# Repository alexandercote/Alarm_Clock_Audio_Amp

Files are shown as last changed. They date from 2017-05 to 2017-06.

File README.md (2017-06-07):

# Alarm_Clock
Design class project where I worked in a group of 3 to implement a music playing alarm clock using a microcontroller board.
Features included displaying time on a 7 segment display, alarm buttons, snooze, ability to change time
and volume control. 

Each subfolder has README's describing the logic behind the decision and pictures demonstrating the contents of the files.

Alarm clock functionality:
- Change the displayed time, date, and alarm time.
- LED's indicate what mode you are currently in. 
     Modes include: Time/Date/Alarm Set, Snooze, and Default.
- Display time in both 12 hour(with AM/PM indicator) and 24 hour 
  formats.
- Choose from different songs placed on the internal storage (a 
  USB drive for our purposes)
- Change the volume of the song using a knob in the center.
- Snooze the alarm both with a push button on the case, and with your 
  phone over bluetooth.
- Use of external power supply (9V battery) for louder audio output.
- Ability to disable the alarm entirely and use it as a clock.

Demonstration of the alarm clock can be found in the following video:
https://www.youtube.com/watch?v=fe28Ro4kcdw

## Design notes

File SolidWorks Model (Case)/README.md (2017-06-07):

# The SolidWorks Case

A case was designed using SolidWorks.
## The Constraints
Designed to be 3D printed, so limited detail and constrained by 3D printing axis.
1. The Box
   - Hold the PCB inside.
   - Slot for 9V DC battery with access to terminal headers to unplug the battery
   - Hole in the back for pushbutton reset on the microcontroller board (STM)
  
The Box:
alarmclockbox_final-1

2. The Front Panel
   - A slot for the 7 segment display
   - Speaker mount
   - Five pushbutton hole slots
   - A potentiometer slot (Same size as pushbuttons)
   
The Front Plate/Panel:
frontplate_final-1

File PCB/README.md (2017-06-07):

# The Circuit

###### Design Limitation:
  - Have the following capacitors: 1nF, 10uF, 470uF and 100 nF
  - Resistors: 5% Resistors.
  - Input Voltage for audio input: [0-3V], DC voltage = 1.5V, with AC voltage = ± 0.3V. 
  - The audio input has source impedance of 20kΩ and has a maximum current source of 25mA.
  - From the data sheet, the impedance of the speaker is 8Ω.

Schematic view of the top hierarchy view, including push button debouncing, with an audio amplifier and LED multiplexer in lower hierarchy schematics.


###### Audio Amplifier:
  - Cascaded Low-Pass and High-Pass Filter to create a BandPass Filter with a pass band of 19.85Hz to 19.4kHz
  - Using the LM386 without its gain pins connected will result in a voltage gain of 20. Since (20 * 0.5V) = 10V, which is higher than 
    our source voltage, we need to voltage divide the input of LM386. (0.5V is the maximum input AC swing). Here, we chose a maximum 
    voltage of 4.5V to make sure the gain stays linear. From that, we found our values for resistors in the voltage divider. A 100kΩ
    potientiometer was used to dynamically set the gain (and therefore the volume)The potentiometer will always show 100 kΩ to the 
    High-Pass Filter, with the LM386 only seeing the resistance set in order to set the volume.

Schematic view of the audio amplifier schematic. Includes a low pass filter cascaded with a high-pass filter, a potentiometer for input voltage control, and an LM386 to amplify.


The schematic view of the LED multiplexing circuit:


The PCB (Two layer):

Top layer PCB view:

top pcb

Top layer view from the manufacturer (OshPark):



Bottom layer PCB view:

bottom pcb
Bottom layer view from the manufacturer:



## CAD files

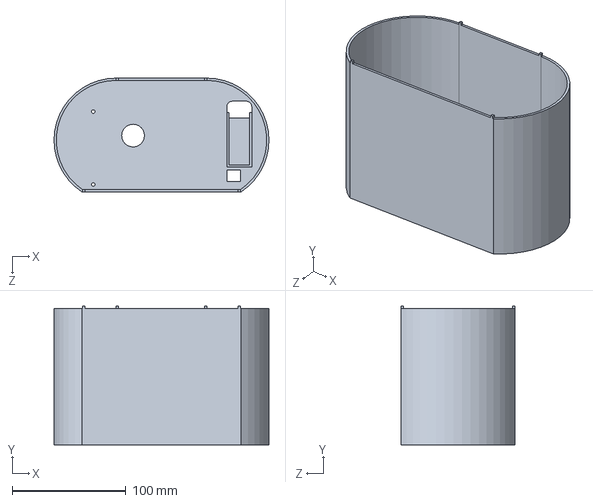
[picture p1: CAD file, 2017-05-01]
SolidWorks Model (Case)/AlarmClockBox_PCB.SLDPRT
189.0 x 122.0 x 100.0 mm

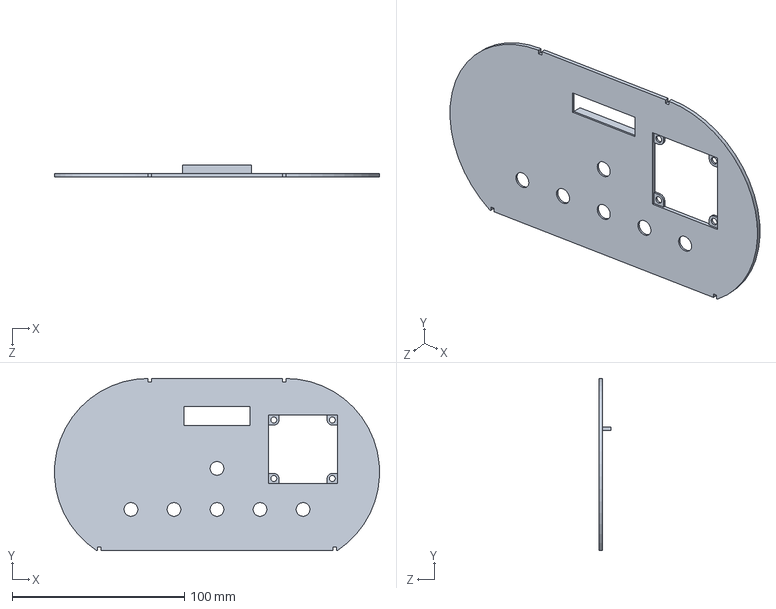
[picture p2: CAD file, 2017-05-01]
SolidWorks Model (Case)/FrontPlate3.SLDPRT
188.9 x 100.0 x 7.00 mm

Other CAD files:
SolidWorks Model (Case)/AlarmClockBox_PCB.SLDDRW
SolidWorks Model (Case)/FrontPlate3.SLDDRW

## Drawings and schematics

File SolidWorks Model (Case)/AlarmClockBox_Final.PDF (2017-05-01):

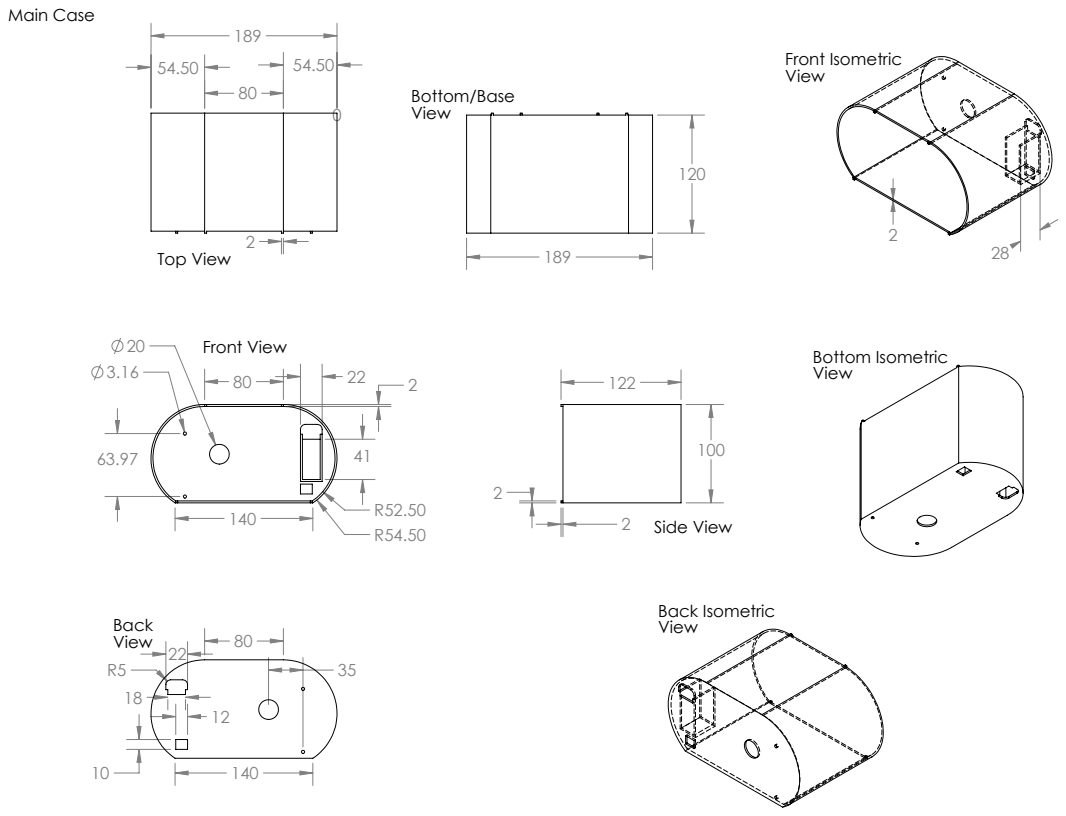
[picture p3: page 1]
Top View; Front Isometric; Back Isometric; Bottom Isometric; Front View; Side View; Main Case

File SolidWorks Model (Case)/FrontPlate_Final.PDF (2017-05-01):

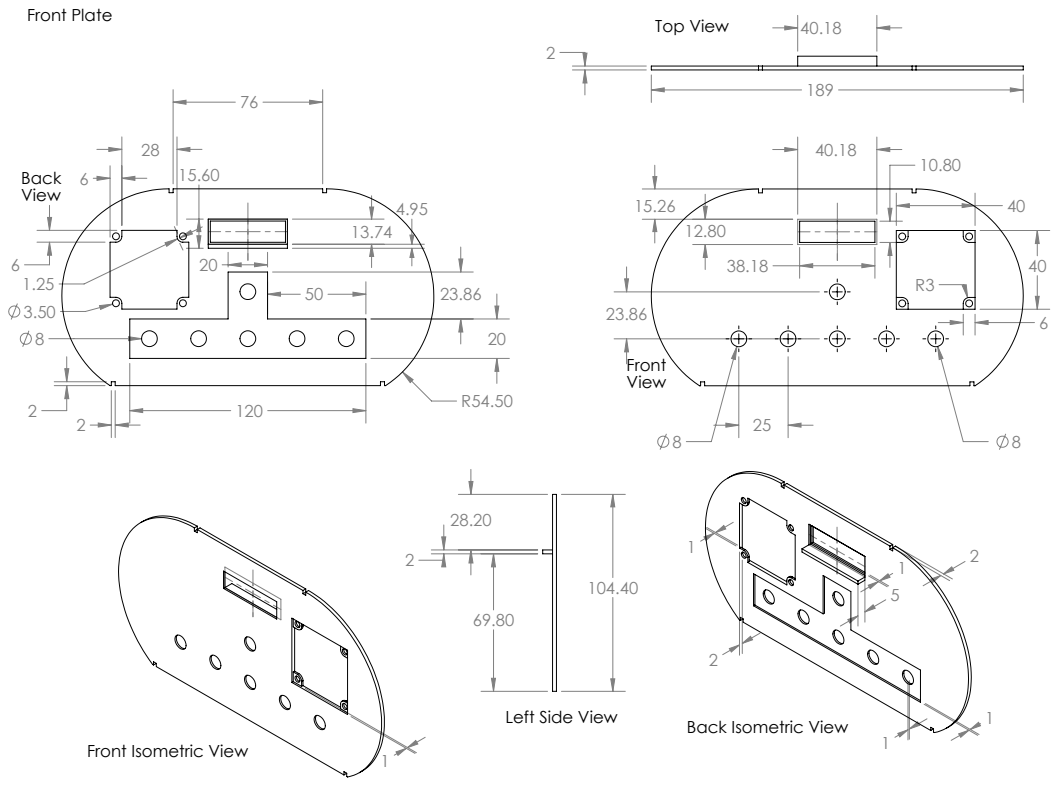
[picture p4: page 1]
Top View; Front Plate

Left Side View

Back Isometric View

1 Front Isometric View

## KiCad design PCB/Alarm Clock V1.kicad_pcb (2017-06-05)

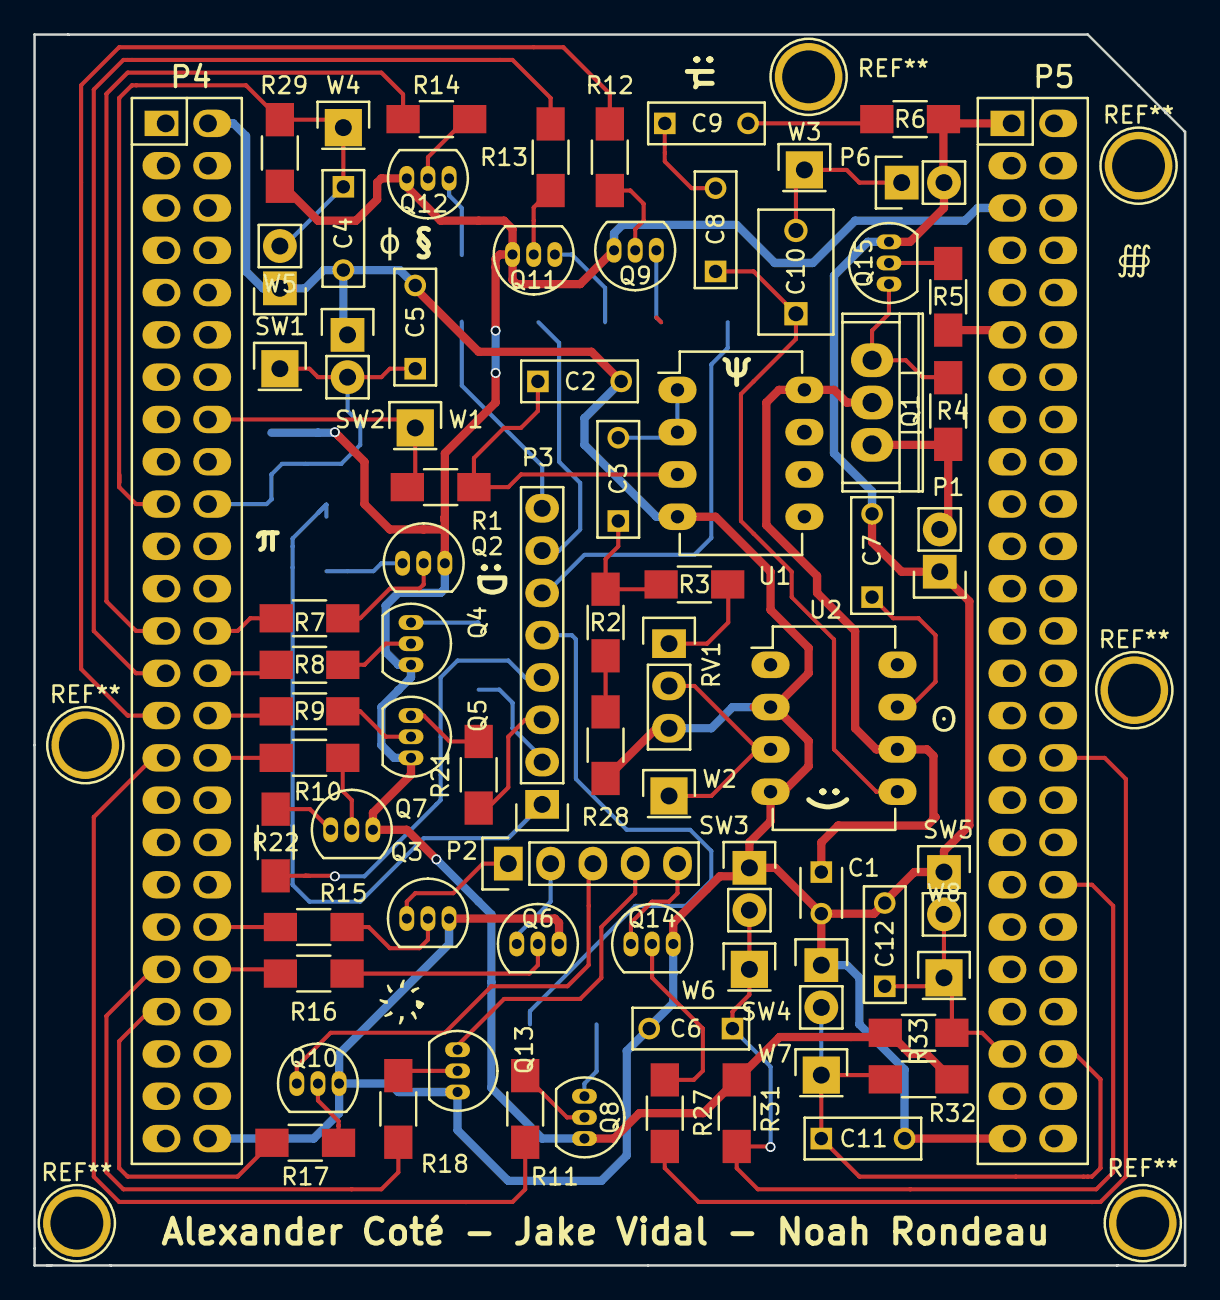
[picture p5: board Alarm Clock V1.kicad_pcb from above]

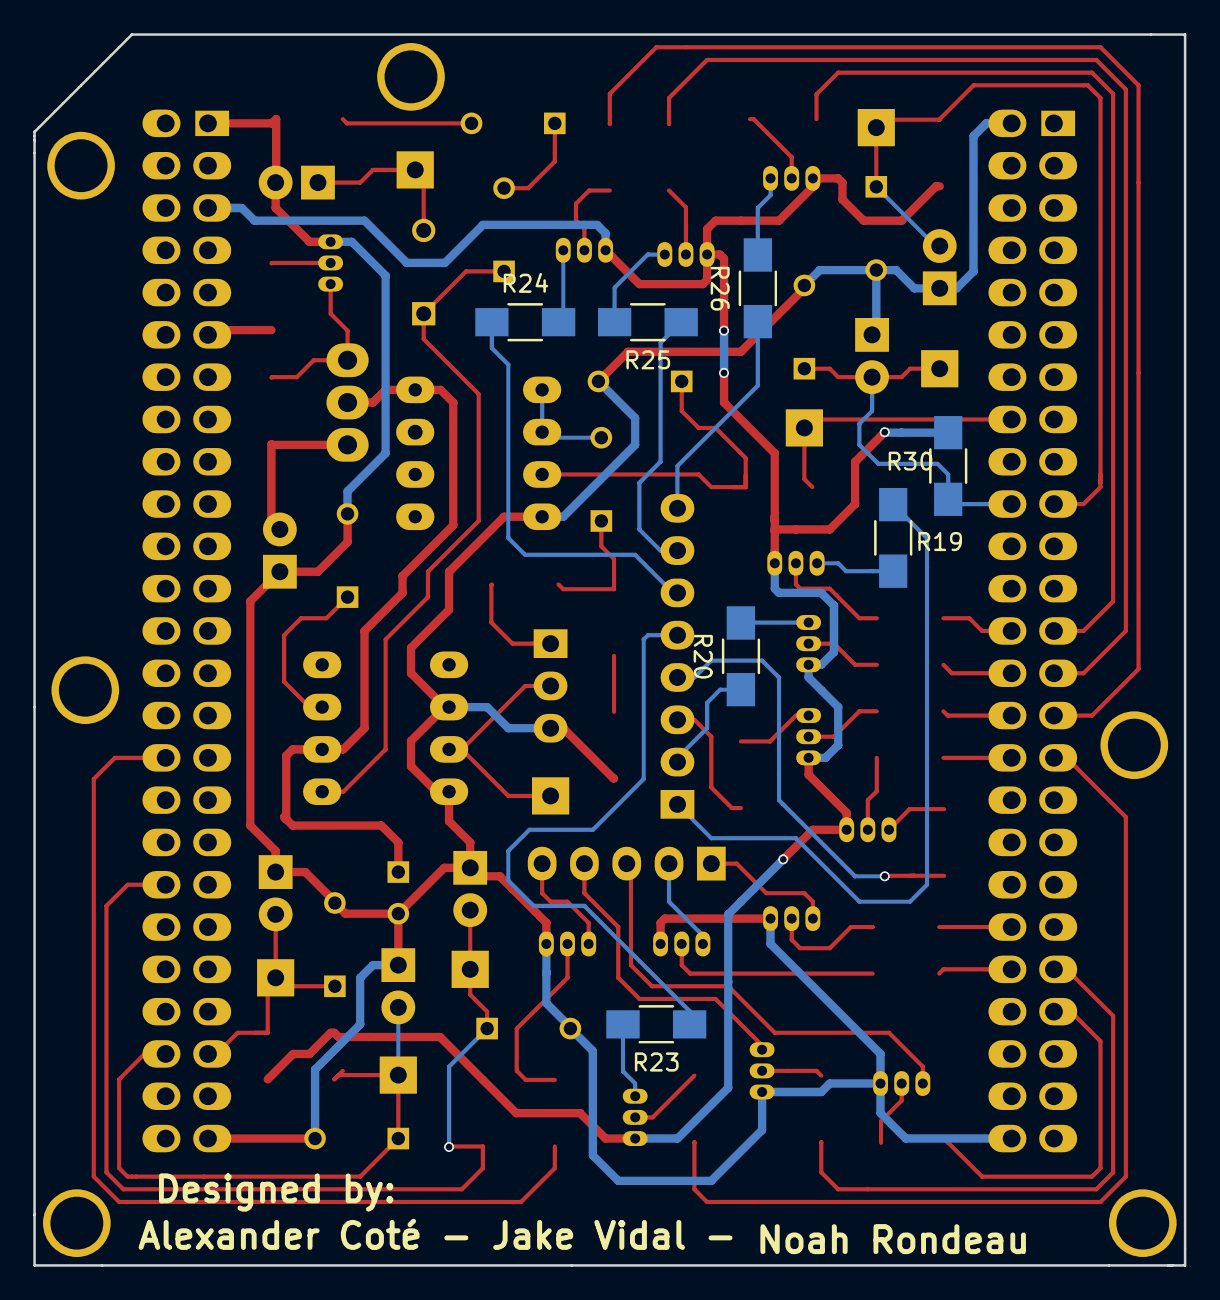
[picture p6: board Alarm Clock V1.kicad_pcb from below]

Board: 2 copper layers, 69.1 x 73.9 mm, 82 parts (7 on the bottom side), 71 nets.

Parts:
C1: 10 uF; C_Disc_D3_P2.5
C2, C3, C4, C5, C6, C7, C8, C9, C11, C12: 100 nF; C_Rect_L7_W2.5_P5
C10: 470 uF; C_Disc_D7.5_P5
P1, P6: CONN_01X02; Pin_Header_Straight_1x02
P2: CONN_01X05; Pin_Header_Straight_1x05
P3: CONN_01X08; Pin_Header_Straight_1x08
P4, P5: STM32_F4_ConnV2
Q1: IRLIB9343; TO-220
Q2, Q4, Q5, Q7, Q8, Q9, Q11, Q12: 2N3906; TO-92_Inline_Narrow_Oval
Q3, Q6, Q10, Q13, Q14, Q15: 2N3904; TO-92_Inline_Narrow_Oval
R1: 82 Ω; R_1206_HandSoldering
R2, R3: 120 kΩ; R_1206_HandSoldering
R4: 100 kΩ; R_1206_HandSoldering
R5, R7, R8, R9, R10, R11, R12, R13, R14, R15, R16, R17, R18, R27: 1 kΩ; R_1206_HandSoldering
R6: 10 Ω; R_1206_HandSoldering
R19, R20, R21, R22, R23, R24, R25, R26: 100 Ω; R_1206_HandSoldering
R28: 6.2 kΩ; R_1206_HandSoldering
R29, R30, R31, R32, R33: 47 kΩ; R_1206_HandSoldering
RV1: POT: 100 kΩ; Pin_Header_Straight_1x03
SW1, SW2, SW3, SW4, SW5: SW_PUSH; Pin_Header_Straight_1x02
U1: LM358N; DIP-8_W7.62mm_LongPads
U2: LM386; DIP-8_W7.62mm_LongPads
W1, W2, W3, W4, W5, W6, W7, W8: TEST_1P; Pin_Header_Straight_1x01

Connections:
/AlarmClockAmplifier/3.3V: P5.11, R5.2
/AlarmClockAmplifier/9V: P1.2, Q1.3, R4.2
/AlarmClockAmplifier/GND: C1.2, C2.2, C4.2, C5.2, C6.2, C7.2, C11.2, C12.2, P1.1, P4.2, P4.50, P5.1, P5.49, P6.2, Q3.3, Q6.3, Q10.3, Q13.3, Q14.3, Q15.3, R6.2, R28.2, RV1.3, SW1.1, SW2.1, SW3.1, SW4.1, SW5.1, U1.4, U2.2, U2.4
/AlarmClockAmplifier/Output: C10.2, P6.1, W3.1
/AlarmClockAmplifier/Signal: P4.16, R1.2, W1.1
/LEDSelect/1: P4.40, R15.2
/LEDSelect/2: P4.42, R16.2
/LEDSelect/3: P4.43, R17.2
/LEDSelect/3V: P5.5, Q2.3, Q4.3, Q5.3, Q7.3, Q8.3, Q9.3, Q11.3, Q12.3, R29.1, R30.1, R31.1, R32.1, R33.1
/LEDSelect/4: P4.41, R18.2
/LEDSelect/5: P5.32, R27.2
/LEDSelect/Digit_1: P2.1, Q3.1
/LEDSelect/Digit_2: P2.2, Q6.1
/LEDSelect/Digit_3: P2.4, Q13.1
/LEDSelect/Digit_4: P2.5, Q14.1
/LEDSelect/P3: P3.4, R22.1
/LEDSelect/P4: P2.3, Q10.1
/LEDSelect/P5: P3.5, R23.1
/LEDSelect/P7: P3.8, R26.1
/LEDSelect/P11: P3.6, R24.1
/LEDSelect/P13: P3.3, R21.1
/LEDSelect/P14: P3.1, R19.1
/LEDSelect/P15: P3.7, R25.1
/LEDSelect/P16: P3.2, R20.1
/LEDSelect/a: P4.26, R7.2
/LEDSelect/b: P4.28, R8.2
/LEDSelect/c: P4.30, R9.2
/LEDSelect/d: P4.32, R10.2
/LEDSelect/e: P4.31, R11.2
/LEDSelect/f: P4.29, R12.2
/LEDSelect/g: P4.27, R13.2
/LEDSelect/h: P4.25, R14.2
/PC4: C5.1, P4.20, R30.2, SW2.2, W5.1
/PC5: C4.1, P4.19, R29.2, SW1.2, W4.1
/PC8: C12.1, P5.45, R33.2, SW5.2, W8.1
/PC9: C11.1, P5.46, R32.2, SW4.2, W7.1
/PC11: C6.1, P5.38, R31.2, SW3.2, W6.1
unnamed: C1.1, Q1.2, U1.8, U2.6
unnamed: C2.1, R1.1, U1.3
unnamed: C3.1, R2.1, R3.1
unnamed: C3.2, U1.1, U1.2
unnamed: C7.1, U2.7
unnamed: C8.2, C9.1
unnamed: C9.2, R6.1
unnamed: C8.1, C10.1, U2.5
unnamed: Q1.1, Q15.1, R4.1
unnamed: Q2.1, R19.2
unnamed: Q2.2, R7.1
unnamed: Q3.2, R15.1
unnamed: Q4.1, R20.2
unnamed: Q4.2, R8.1
unnamed: Q5.1, R21.2
unnamed: Q5.2, R9.1
unnamed: Q6.2, R16.1
unnamed: Q7.1, R22.2
unnamed: Q7.2, R10.1
unnamed: Q8.1, R23.2
unnamed: Q8.2, R11.1
unnamed: Q9.1, R24.2
unnamed: Q9.2, R12.1
unnamed: Q10.2, R17.1
unnamed: Q11.1, R25.2
unnamed: Q11.2, R13.1
unnamed: Q12.1, R26.2
unnamed: Q12.2, R14.1
unnamed: Q13.2, R18.1
unnamed: Q14.2, R27.1
unnamed: Q15.2, R5.1
unnamed: R2.2, R28.1
unnamed: R3.2, RV1.1
unnamed: RV1.2, U2.3, W2.1

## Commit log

2017-05-01 Added SolidWorks case files and pdf description
    [AlarmClockBox_PCB.SLDDRW, AlarmClockBox_PCB.SLDPRT, FrontPlate3.SLDDRW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]
2017-05-01 Added PCB Files
    [Alarm Clock V1.kicad_pcb, Alarm Clock V1.sch, AlarmClockAmplifier.sch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]
2017-06-05 Updated PCB - Final version that was sent to fab
    [Alarm Clock V1.kicad_pcb, Alarm Clock V1.sch]
